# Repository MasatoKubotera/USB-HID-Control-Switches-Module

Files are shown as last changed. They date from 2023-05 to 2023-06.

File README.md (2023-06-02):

<html lang="en">

<head>
	<meta charset="uft-8">
	<meta name="author" content="Masato Kubotera">
    <meta name="description" content="">
</head>

<body>
    <p><strong>This product is currently under development!</strong></p>
	<h1>USB-HID Control Switches Module</h1>
        <p>
            This product is a USB-HID module equipped with two tactile switches. The module is recognized as a game controller when connected to a computer with an Arduino compatible board equipped with ATmega32U4. Using the sample firmware, a press of the two tactile switches on the board is recognized as a press of game controller buttons 1 and 2, respectively.<br>
            This product is developed as a control switches for <a href="https://github.com/SUSTAINA-OP">SUSTAINA-OP<sup>TM</sup></a>, it is used to start or stop the robot's behavior.
        </p>
	<h2>Features Rev. 1</h2>
        <p>
            <table>
                <tr>
                    <th>Top Surface of PCB</th>
                    <th>Bottom Surface of PCB</th>
                    <th>Assembled Electronic Components</th>
                </tr>
                <tr>
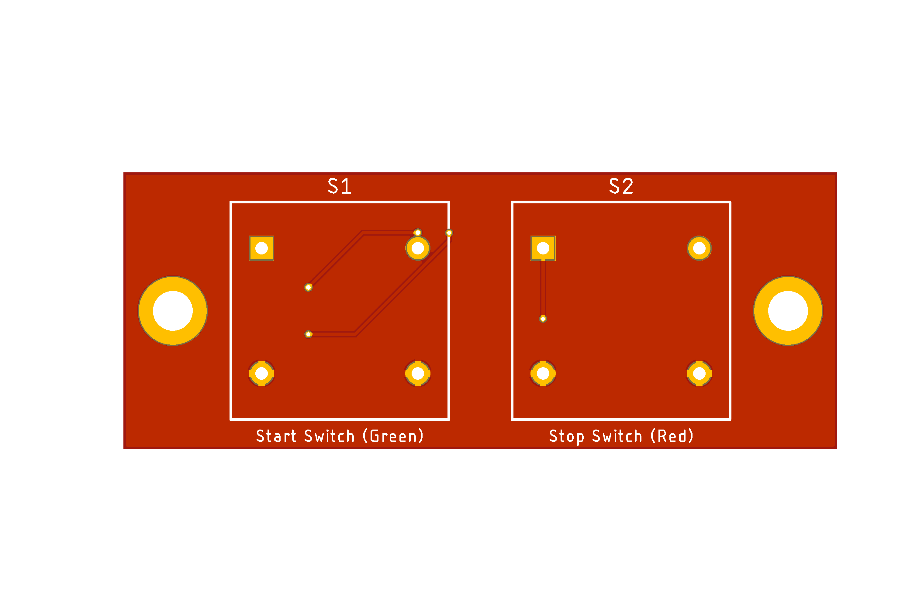
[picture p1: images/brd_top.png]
                    <td></td>
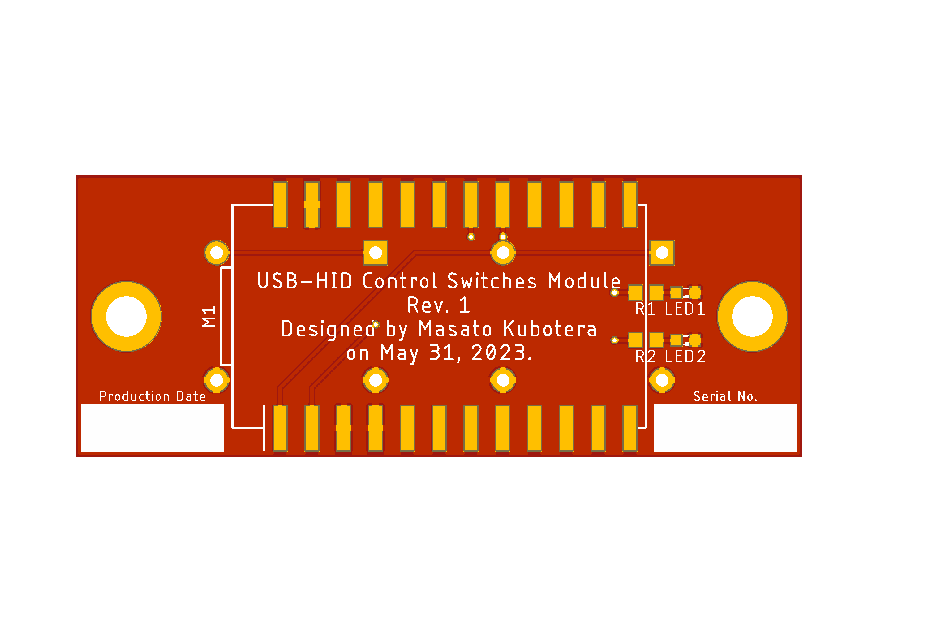
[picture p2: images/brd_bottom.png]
                    <td></td>
                    <td></td>
                </tr>
            </table>
        </p>
    <h3>PCB</h3>
        <p>
            <ul>
                <li>58 mm x 22.5 mm PCB layout</li>
                <li>2 x ø3.2 Mounting Holes</li>
            </ul>
        </p>
    <h3>Dual Tactile Switches</h3>
        <p>
            NKK Switches JF Series (Green: JF15SP1F, Red: JF15SP1C)
            <ul>
                <li>Contact Rating: 0.05A @ 24VDC</li>
                <li>Circuits: Off-Mom</li>
                <li>Outline: 17.70mm x 17.70mm</li>
                <li>Operating Force: 300gf</li>
            </ul>
        </p>
	<h2>Development Environments</h2>
    <p>
        This product is designed with the following software.
            <ul>
                <li><a href="https://www.autodesk.com/products/eagle/overview">Autodesk Eagle 9.6.2</a></li>
            </ul>
    </p>
    <h2>Repository Contents</h2>
        <p>
            <dl>
                <dt><a href="/images">\images</a></dt>
                <dd>PCB preview images and capture of design screen</dd>
                <dt><a href="/libraries">\libraries</a></dt>
                <dd>Libraries used in Autodesk Eagle design</dd>
                <dt><a href="/documents">\documents</a> </dt>
                <dd>Documentation for making and using this product</dd>
                <dt><a href="/pcb_order">\pcb_order</a> </dt>
                <dd>Gerber data and documentation for ordering PCB</dd>
                <dt><a href="/firmware">\firmware</a> </dt>
                <dd>Sample firmware to be written to the microcontroller board</dd>
                <dt><a href="/schematic.pdf">schematic.pdf</a></dt>
                <dd>Circuit diagram of this product</dd>
                <dt>*.brd</dt>
                <dd>Board wiring design file by Autodesk Eagle</dd>
                <dt>*.sch</dt>
                <dd>Circuit diagram design file by Autodesk Eagle</dd>
                <dt><a href="/.gitignore">.gitignore</a></dt>
                <dd>A file that tells Git not to track a particular file</dd>
                <dt><a href="/LICENSE">LICENSE</a></dt>
                <dd>License to use this product</dd>
            </dl>
        </p>
    <h2>Documentation</h2>
        <p>
            The following documents are available for this product.
            <ul>
                <li><a href="/documents/BOM.md">\document\BOM.md</a>: List of electronic components assembled on the PCB</li>
            </ul>
        </p>
    <h2>References</h2>
        <p>
            This product was designed with reference to the following products.
            <ul>
                <li></li>
            </ul>
        </p>
    <h2>Contact</h2>
        <p>
            If you have any questions, please contact the designer of this product, Masato Kubodera, by <a href="mailto:masato.kubotera@sustaina-op.com">e-mail</a>.<br>
            E-mail: <a href="mailto:masato.kubotera@sustaina-op.com">masato.kubotera@sustaina-op.com</a>
        </p>
    <h2>License Information</h2>
        <p>
            This product is open source. Please review the <a href="/LICENSE">LICENSE</a> for license information.<br>
            <br>
            This product by Masato Kubotera is licensed under a <a href="http://creativecommons.org/licenses/by-nc-sa/4.0/">Creative Commons Attribution-NonCommercial-ShareAlike 4.0 International License</a>.
        </p>
</body>
</html>

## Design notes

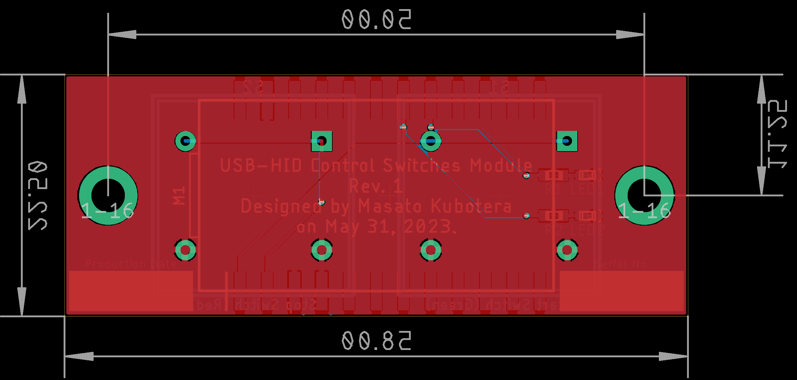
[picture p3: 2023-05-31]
images/brd.png

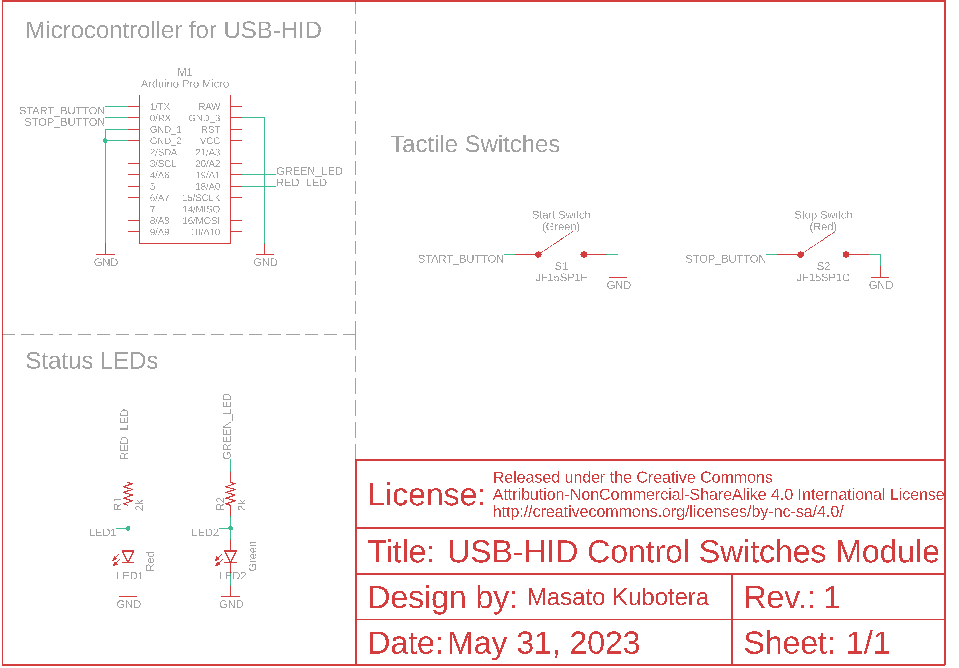
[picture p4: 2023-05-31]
images/sch.png

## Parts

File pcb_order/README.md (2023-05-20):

<html lang="en">

<head>
	<meta charset="uft-8">
	<meta name="author" content="Masato Kubotera">
    <meta name="description" content="">
</head>

<body>
	<h1>PCB Order</h1>
        <p>
            PCB/PCBA ordering were outsourced to <a href="https://jlcpcb.com/">JLCPCB</a>.<br>
            The following files were used to generate files for PCB/PCBA orders.
            <ul>
                <li>Eagle Design File:
                    <a href="https://github.com/JLCPCB/jlcpcb-eagle/blob/master/design%20rules/jlcpcb-2layers.dru">jlcpcb-2layers.dru</a>
                </li>
                <li>Eagle CAM File:
                    <a href="https://github.com/JLCPCB/jlcpcb-eagle/blob/master/cam/jlcpcb_2_layer_v9.cam">jlcpcb_2_layer_v9.cam</a>
                </li>
                <li>BOM/CPL Exporter ULPs:
                    <a href="https://github.com/JLCPCB/jlcpcb-eagle/blob/master/ulps/jlcpcb_smta_exporter.ulp">jlcpcb_smta_exporter.ulp</a>
                </li>
            </ul>
            These are distributed in <a href="https://github.com/JLCPCB/jlcpcb-eagle">github.com/JLCPCB/jlcpcb-eagle</a>.<br>
        </p>
    <h2>PCB Order Specifications</h2>
        <p>           
            <table>
                <tr>
                    <th>PCB Top Image</th>
                    <th>PCB Bottom Image</th>
                </tr>
                <tr>
                    <td></td>
                    <td></td>
                </tr>
            </table>
            The following  files used to order the PCB and their specifications. 
            <ul>
                <li>Gerber data: <a href="Gerber_date.zip">Gerber_date.zip</a></li>
            </ul>
            This product is recommended to assemble components with a soldering iron without using a PCB Stencil.<br>
            <details close>
                <summary>Click for more specifications</summary>
                <ul>                
                    <li>Base Material: FR-4</li>
                    <li>Layers: 2</li>
                    <li>Dimension: 58 mm* 22.5 mm</li>
                    <li>Product Type: Industrial/Consumer electronics</li>
                    <li>Different Design: 1</li>
                    <li>Delivery Format: Single PCB</li>
                    <li>PCB Thickness: 1.6</li>
                    <li>Impedance Control: no</li>
                    <li>PCB Color: Red</li>
                    <li>Silkscreen: White</li>
                    <li>Surface Finish: HASL(with lead)</li>
                    <li>Outer Copper Weight: 1 oz</li>
                    <li>Via Covering: Tented</li>
                    <li>Board Outline Tolerance: ±0.2mm(Regular)</li>
                    <li>Confirm Production file: No</li>                
                    <li>Remove Order Number: Yes</li>
                    <li>Deburring/Edge rounding: No</li>
                    <li>Flying Probe Test: Fully Test</li>
                    <li>Gold Fingers: No</li>
                    <li>Castellated Holes: No</li>
                    <li>4-Wire Kelvin Test: No</li>
                    <li>Paper between PCBs: No</li>
                    <li>Appearance Quality: IPC Class 2 Standard</li>
                    <li>Silkscreen Technology: Ink-jet/Screen Printing</li>
                    <li>Package Box: With JLCPCB logo</li>
                </ul>
            </details>
        </p>
    </body>
</html>

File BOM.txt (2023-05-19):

Qty Value         Device        Package       Parts Description 
1   JF15SP1C      JF15SP1C      JF15SP1       S2                
1   JF15SP1F      JF15SP1F      JF15SP1       S1                
1   PRO_MICRO_SMD PRO_MICRO_SMD PRO_MICRO_SMD M1

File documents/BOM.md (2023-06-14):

<html lang="en">

<head>
	<meta charset="uft-8">
	<meta name="author" content="Masato Kubotera">
    <meta name="description" content="">
</head>

<body>
	<h1>BOM</h1>
        <p>
        The following electronic components are used for assembly on the PCB.
        <table>
                <tr>
                    <th>Top Designator</th>
                    <th>MFR.Part #</th>
                    <th>Distributor / Part #</th>
                    <th>Manufacturer</th>
                    <th>Part Detail</th>
                </tr>
                <tr>
                    <td>S1</td>
                    <td>JF15SP1F</td>
                    <td><a href="https://www.mouser.jp/ProductDetail/633-JF15SP1F">Mouser / 633-JF15SP1F</a></td>
                    <td><a href="https://www.nkkswitches.com/wp-content/themes/impress-blank/search/inc/part.php?part_no=JF15SP1F">NKK Switches</a></td>
                    <td>Tactile Switche Through-hole OFF-(ON) Green</td>
                </tr>
                <tr>
                    <td>S2</td>
                    <td>JF15SP1C</td>
                    <td><a href="https://www.mouser.jp/ProductDetail/633-JF15SP1C">Mouser / 633-JF15SP1C</a></td>
                    <td><a href="https://www.nkkswitches.com/wp-content/themes/impress-blank/search/inc/part.php?part_no=JF15SP1C">NKK Switches</a></td>
                    <td>Tactile Switche Through-hole OFF-(ON) Red</td>
                </tr>
                <tr>
                    <td>M1</td>
                    <td>DEV-12640</td>
                    <td><a href="https://www.mouser.jp/ProductDetail/474-DEV-12640">Mouser / 474-DEV-12640</a></td>
                    <td><a href="https://www.sparkfun.com/products/12640">sparkfun</a></td>
                    <td>Arduino Compatible Board with ATmega32U4</td>
                </tr>
                <tr>
                    <td>M1</td>
                    <td>110-87-624-41-105101</td>
                    <td><a href="https://jp.rs-online.com/web/p/dil-sockets/7020597">RS / 702-0597</a></td>
                    <td><a href="https://www.precidip.com/pview/110-PP-624-41-105101.html">Preci-Dip</a></td>
                    <td>Pin Header SMD 2.54mm Pitch 1A 10mΩ 150V</td>
                </tr>
                <tr>
                    <td>M1</td>
                    <td>PHA-1x40SG</td>
                    <td><a href="https://akizukidenshi.com/catalog/g/gC-06631/">Akizuki / C-06631</a></td>
                    <td>Useconn Electronics Ltd.</td>
                    <td>Pin Header Straight 2.54mm Pitch 2A 20mΩ 500V</td>
                </tr>
                <tr>
                    <td>R1,R2</td>
                    <td>RC0603FR-102KL</td>
                    <td><a href="https://www.mouser.jp/ProductDetail/603-RC0603FR-102KL/">Mouser / 603-RC0603FR-102KL</a></td>
                    <td>YAGEO</td>
                    <td>Thick Film Resistor SMD 2kΩ 1/10W ±1% 0603</td>
                </tr>
                <tr>
                    <td>LED1,LED2</td>
                    <td>150060VS86000</td>
                    <td><a href="https://www.mouser.jp/ProductDetail/710-150060VS86000">Mouser / 710-150060VS86000</a></td>
                    <td><a href="https://www.we-online.com/components/products/datasheet/150060VS86000.pdf">Wurth Elektronik</a></td>
                    <td>Pin Header Straight 2.54mm Pitch 2A 20mΩ 500V</td>
                </tr>
            </table>
        </p>
</body>
</html>

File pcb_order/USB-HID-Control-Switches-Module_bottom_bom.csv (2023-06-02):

Comment | Designator | Footprint | LCSC Part #
2k | R1 R2 | R0603 | C105576
Green | LED2 | SML0603 | C2922668
PRO_MICRO_SMD | M1 | PRO_MICRO_SMD
Red | LED1 | SML0603 | C253533

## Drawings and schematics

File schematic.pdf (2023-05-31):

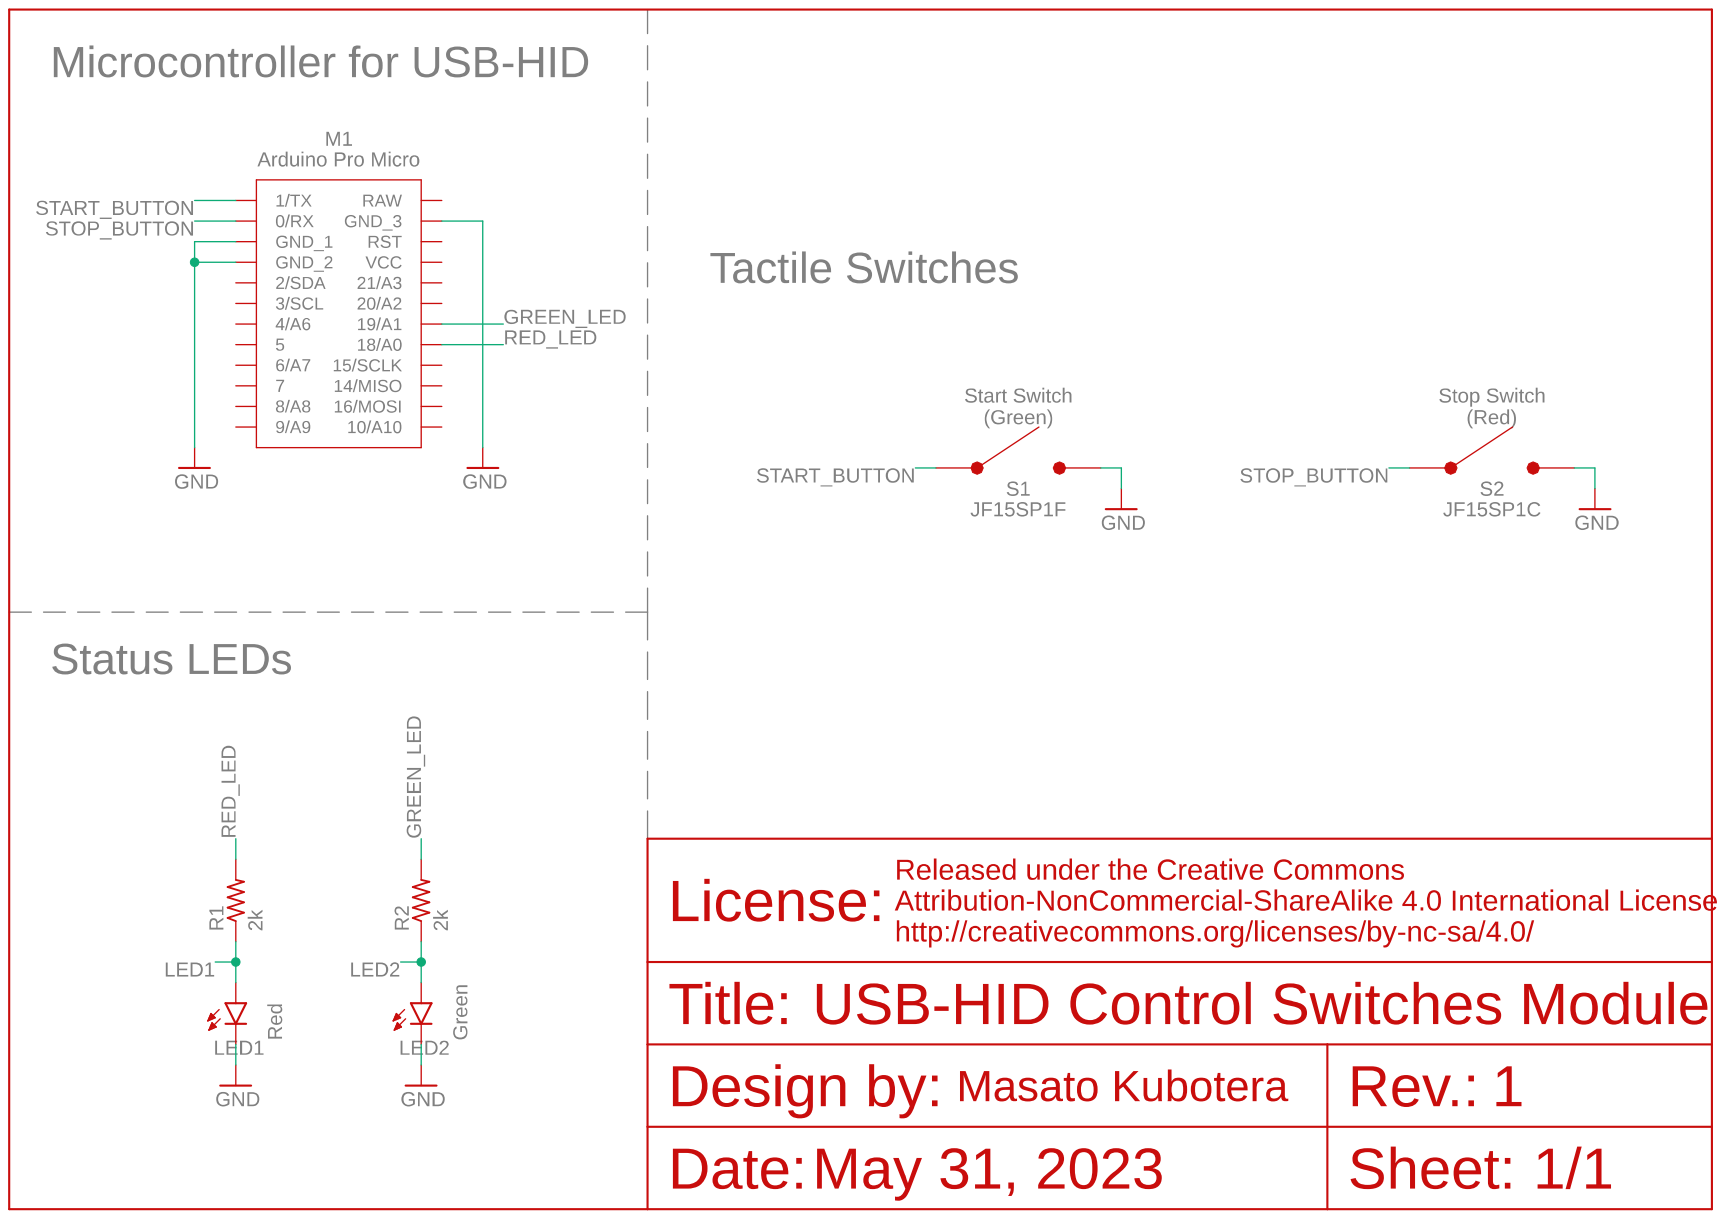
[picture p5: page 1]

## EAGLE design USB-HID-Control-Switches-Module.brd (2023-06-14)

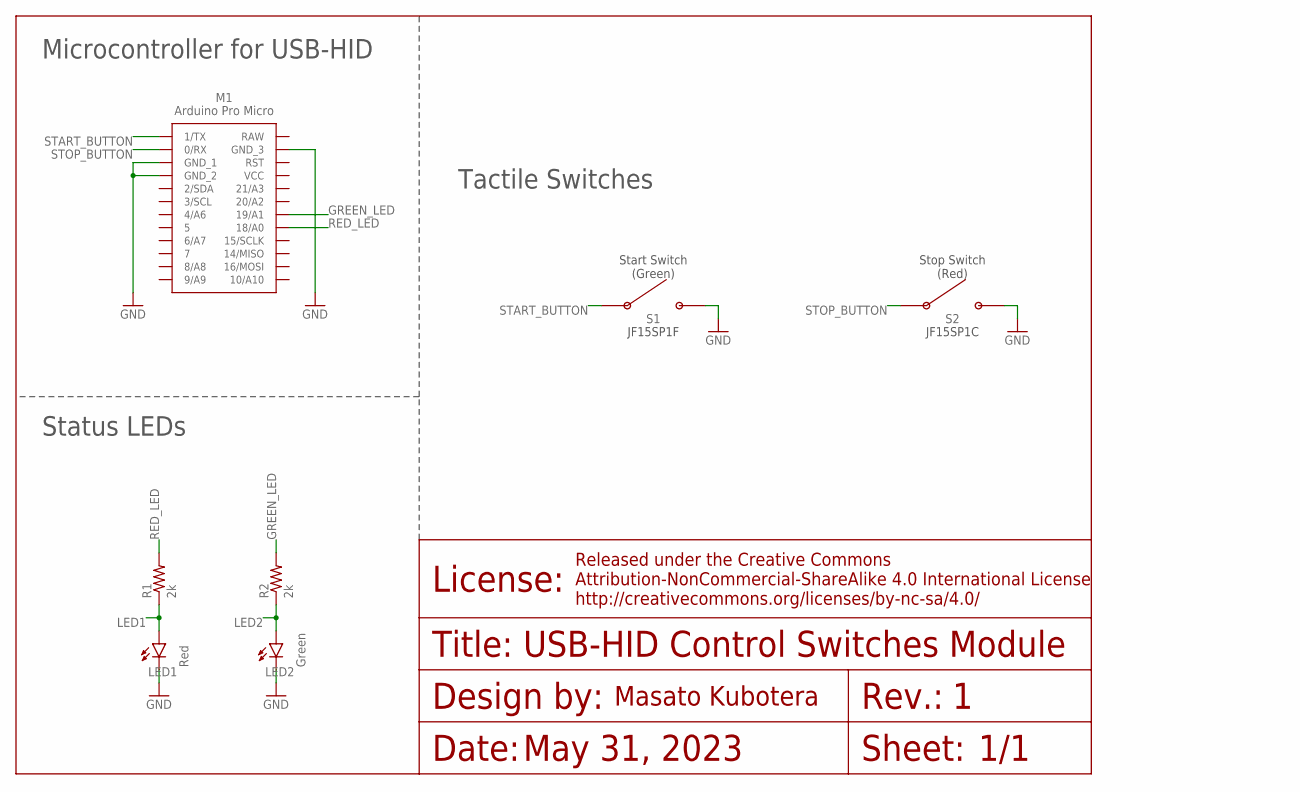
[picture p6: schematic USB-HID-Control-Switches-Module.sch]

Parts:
LED1: Red; SML0603
LED2: Green; SML0603
M1: PRO_MICRO_SMD
R1, R2: 2k; R0603
S1: JF15SP1F; JF15SP1
S2: JF15SP1C; JF15SP1

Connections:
GND: LED1.C, LED2.C, M1.3 (GND_1), M1.4 (GND_2), M1.23 (GND_3), S1.3, S1.4, S2.3, S2.4
GREEN_LED: M1.18 (19/A1), R2.2
LED1: LED1.A, R1.1
LED2: LED2.A, R2.1
RED_LED: M1.17 (18/A0), R1.2
START_BUTTON: M1.1 (1/TX), S1.1, S1.2
STOP_BUTTON: M1.2 (0/RX), S2.1, S2.2

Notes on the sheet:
Start Switch (Green)
Stop Switch (Red)
Microcontroller for USB-HID
Tactile Switches
1/1
May 31, 2023
USB-HID Control Switches Module
Status LEDs

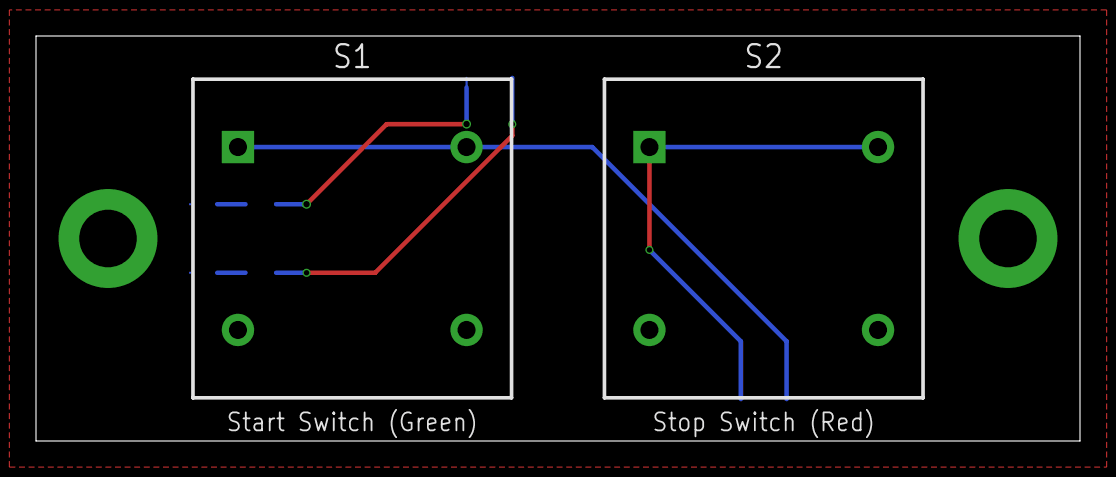
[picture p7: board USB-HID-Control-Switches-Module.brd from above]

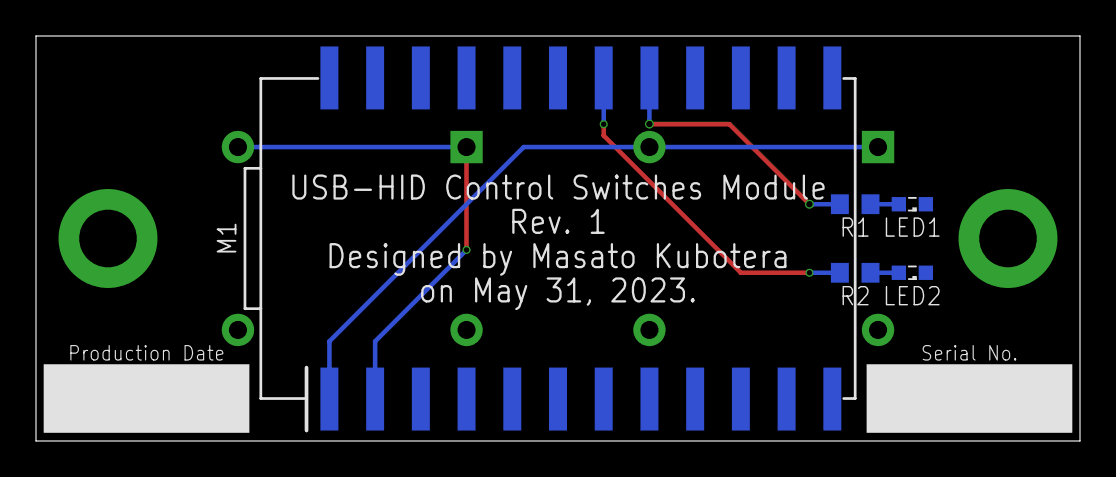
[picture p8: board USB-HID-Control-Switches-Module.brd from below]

Board: 2 copper layers, 58.0 x 22.5 mm, 7 parts (5 on the bottom side), 7 nets.

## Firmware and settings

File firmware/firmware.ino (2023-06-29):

#include "./src/Joystick.h"

Joystick_ Joystick;

/*
   The correspondence between physical buttons and output buttons is as follows.
   stop_button : Stop Button  / pin num : 0 / int.2
   start_button : Start Button / pin num : 1 / int.3
*/

// button state 0: release ,1:press
volatile int stop_button_state = 0;
volatile int start_button_state = 0;

void setup() {
  // Initialize Button Pins
  pinMode(0, INPUT_PULLUP); // Stop Button
  pinMode(1, INPUT_PULLUP); // Start Button

  // Initialize Joystick Library
  Joystick.begin();

  // Initialize external interrupts
  attachInterrupt(2, stop_button_press, FALLING); // pin num 0 -> int.2 // Stop
  attachInterrupt(3, start_button_press, FALLING); // pin num 1 -> int.3 // Start
  /*
     Refer to the following URL for attachInterrupt.
     https://www.arduino.cc/reference/en/language/functions/external-interrupts/attachinterrupt/
  */
}

void loop() {
  if (stop_button_state == 1 && PIND & _BV(2)) {
    Joystick.setButton(1, false);
    stop_button_state = 0;
    PORTF &= ~_BV(7);
  }

  if (start_button_state == 1 && PIND & _BV(3)) {
    Joystick.setButton(2, false);
    start_button_state = 0;
    PORTF &= ~_BV(6);
  }
}

void stop_button_press() {
  Joystick.setButton(1, true);
  stop_button_state = 1;
  //PORTF |=  _BV(7);
  analogWrite(A0, 255);
}

void start_button_press() {
  Joystick.setButton(2, true);
  start_button_state = 1;
  //PORTF |=  _BV(6);
  analogWrite(A1, 255);
}

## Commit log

2023-05-19 Initial upload
    [USB-HID-Control-Switches-Module.brd, USB-HID-Control-Switches-Module.sch]
2023-05-20 Change the mounting orientation of the microcontroller board
    [USB-HID-Control-Switches-Module.brd]
2023-05-20 Added documentation and data on PCB order
2023-05-31 Additional LED for status check
    [USB-HID-Control-Switches-Module.brd, USB-HID-Control-Switches-Module.sch]
2023-06-02 Add files for PCBA (not used)
    [USB-HID-Control-Switches-Module_bottom_bom.csv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]
2023-06-14 Update README.md for additional LED for status check
2023-06-14 Changed the color of the board preview to a shade closer to the actual color
    [USB-HID-Control-Switches-Module.brd]
2023-06-29 Changed to firmware using status indicator LEDs

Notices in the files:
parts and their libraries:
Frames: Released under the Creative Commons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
